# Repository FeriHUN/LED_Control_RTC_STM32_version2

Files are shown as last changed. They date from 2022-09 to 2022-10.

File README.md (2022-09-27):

# LED_Control_RTC_STM32_version2
20 channel 16 bit PWM LED strip brightness controller for 12-24V applications with RS485 connectivity

[Expander board link](https://github.com/FeriHUN/LED_Control_RTC_STM32_version2_Expander)



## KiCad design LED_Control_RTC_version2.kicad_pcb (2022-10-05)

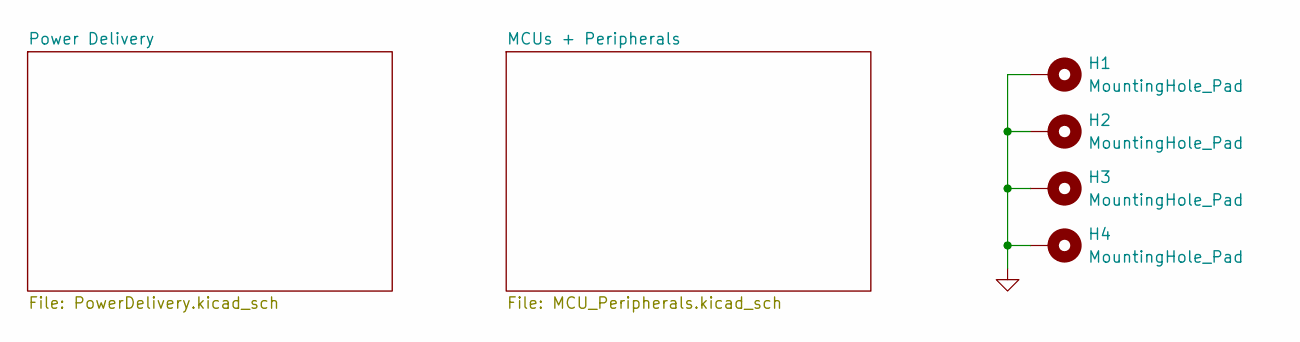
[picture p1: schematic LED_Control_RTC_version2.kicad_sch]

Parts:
H1, H2, H3, H4: MountingHole_Pad; MountingHole_3.2mm_M3_Pad_Via

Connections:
GND: H1.1, H2.1, H3.1, H4.1; also elsewhere on the board

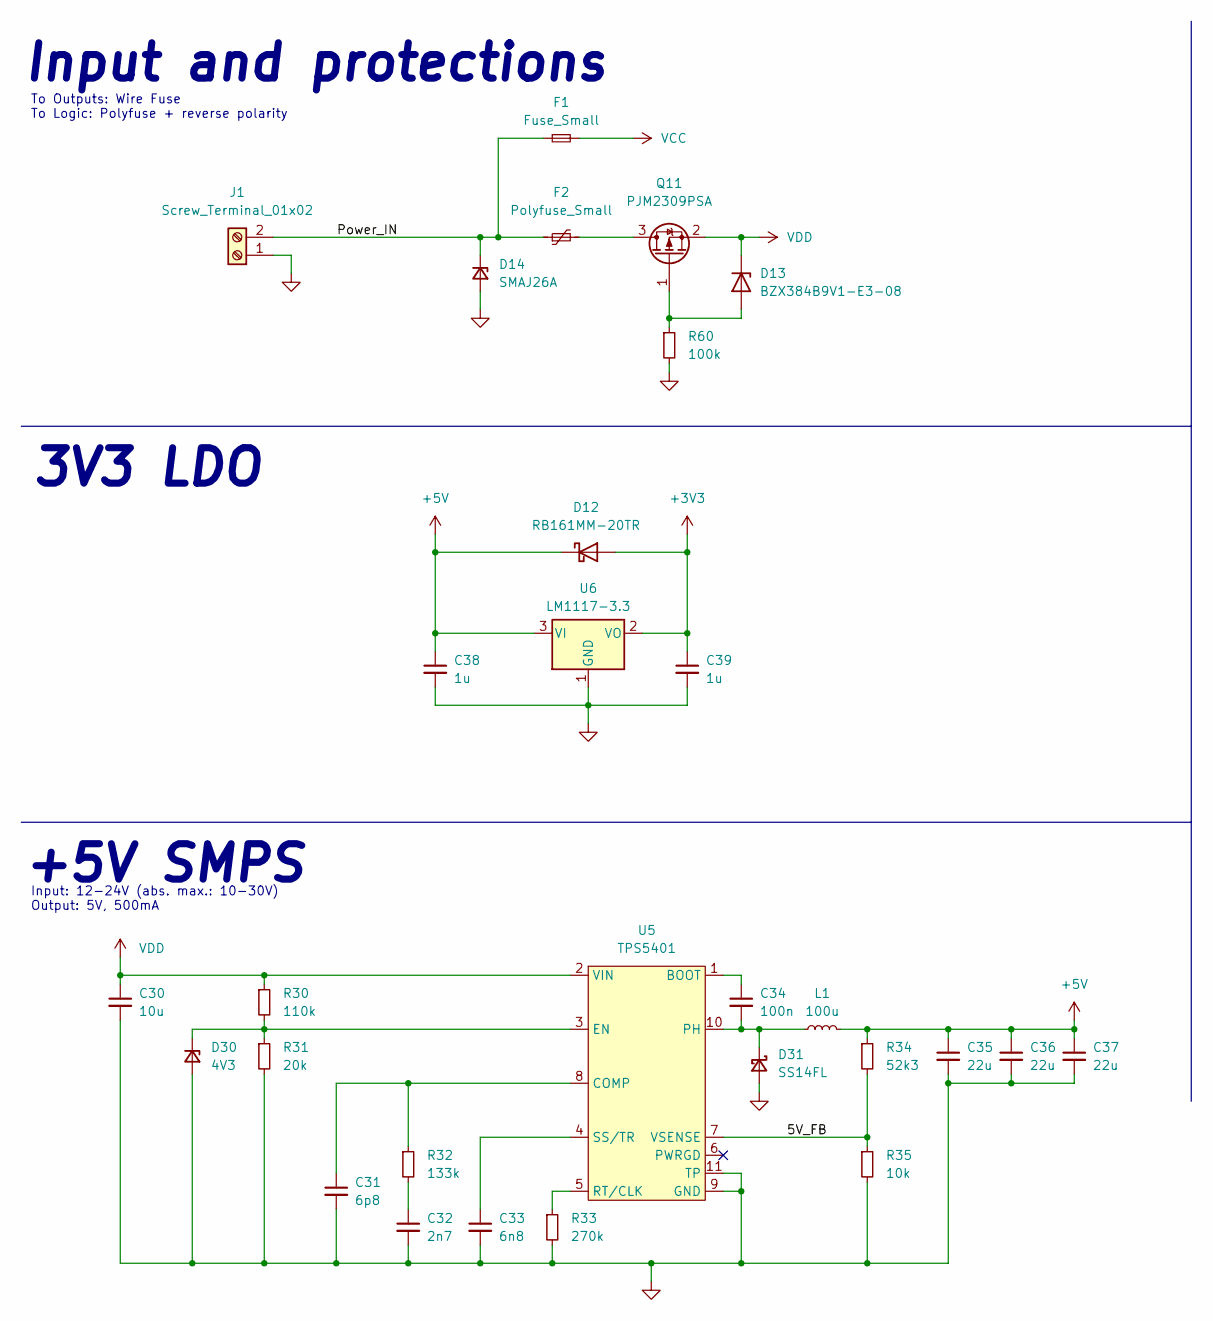
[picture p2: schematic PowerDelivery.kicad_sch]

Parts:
C30: 10u; R_1206_3216Metric
C31: 6p8; R_0603_1608Metric
C32: 2n7; R_0603_1608Metric
C33: 6n8; R_0603_1608Metric
C34: 100n; R_0603_1608Metric
C35, C36, C37: 22u; R_1206_3216Metric
C38, C39: 1u; C_0603_1608Metric
D12: RB161MM-20TR; D_SOD-123F
D13: BZX384B9V1-E3-08; D_SOD-323
D14: SMAJ26A; D_SMA
D30: 4V3; D_SOD-123
D31: SS14FL; D_SMA
F1: Fuse_Small; Fuseholder_Littelfuse_100_series_5x20mm
F2: Polyfuse_Small; Fuse_1812_4532Metric
J1: Screw_Terminal_01x02; PhoenixContact_MC_1,5_2-GF-5.08_1x02_P5.08mm_Horizontal_Thr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
L1: 100u; ABG08A40M101
Q11: PJM2309PSA; SOT-23
R30: 110k; R_0603_1608Metric
R31: 20k; R_0603_1608Metric
R32: 133k; R_0603_1608Metric
R33: 270k; R_0603_1608Metric
R34: 52k3; R_0603_1608Metric
R35: 10k; R_0603_1608Metric
R60: 100k; R_0402_1005Metric
U5: TPS5401; MSOP-10-1EP_3x3mm_P0.5mm_EP1.68x1.88mm_ThermalVias
U6: LM1117-3.3; SOT-223-3_TabPin2

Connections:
+5V: C35.1, C36.1, C37.1, C38.1, D12.1 (K), L1.2, R34.1, U6.3 (VI); also elsewhere on the board
/Power Delivery/5V_FB: R34.2, R35.1, U5.7 (VSENSE)
/Power Delivery/Power_IN: D14.1 (K), F1.1, F2.1, J1.2
GND: C30.2, C31.2, C32.2, C33.2, C35.2, C36.2, C37.2, C38.2, C39.2, D14.2 (A), D30.2 (A), D31.2 (A), J1.1, R31.2, R33.2, R35.2, R60.2, U5.9 (GND), U5.11 (TP), U6.1 (GND); also elsewhere on the board
unnamed: C31.1, R32.1, U5.8 (COMP)
unnamed: C32.1, R32.2
unnamed: C33.1, U5.4 (SS/TR)
unnamed: C34.1, U5.1 (BOOT)
unnamed: C34.2, D31.1 (K), L1.1, U5.10 (PH)
unnamed: D13.2 (A), Q11.1 (G), R60.1
unnamed: D30.1 (K), R30.2, R31.1, U5.3 (EN)
unnamed: F2.2, Q11.3 (D)
unnamed: R33.1, U5.5 (RT/CLK)
VCC: F1.2; also elsewhere on the board
VDD: C30.1, D13.1 (K), Q11.2 (S), R30.1, U5.2 (VIN)

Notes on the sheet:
+5V SMPS
Input: 12-24V (abs. max.: 10-30V) Output: 5V, 500mA
3V3 LDO
Input and protections
To Outputs: Wire Fuse To Logic: Polyfuse + reverse polarity

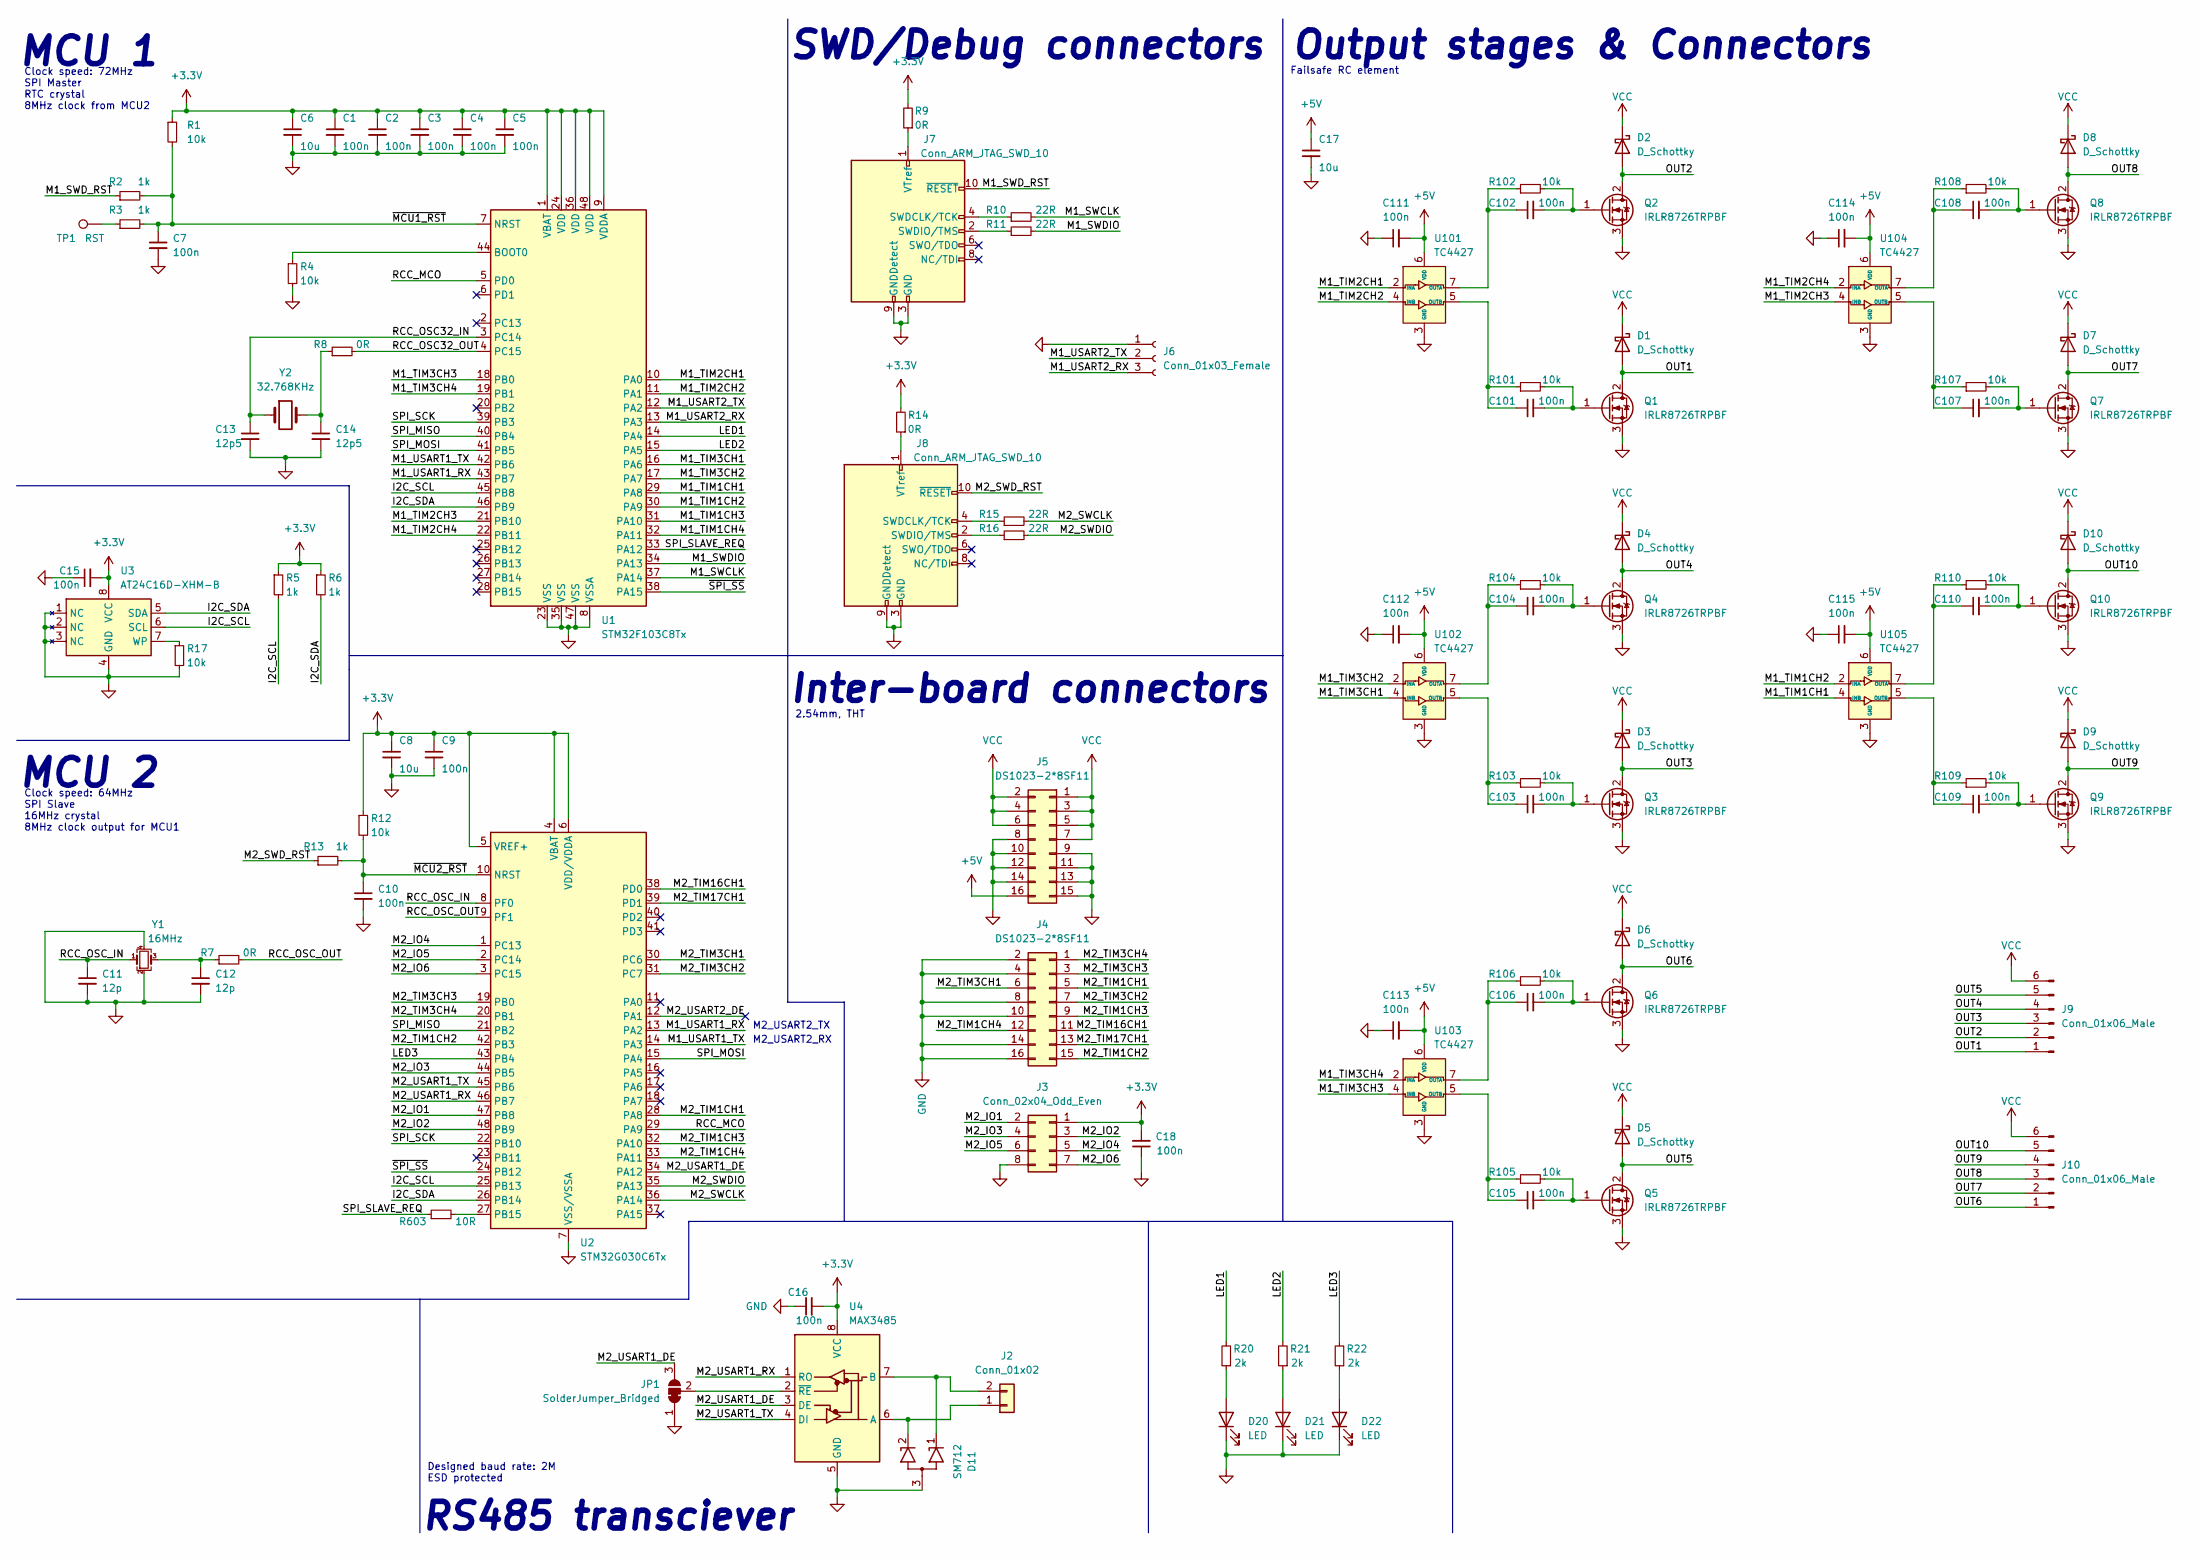
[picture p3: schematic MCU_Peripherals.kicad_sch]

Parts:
C1, C2, C3, C4, C5, C7, C9, C10, C15, C16, C18, C101, C102, C103, C104, C105, C106, C107, C108, C109, C110, C111, C112, C113, C114, C115: 100n; C_0402_1005Metric
C6, C8, C17: 10u; R_1206_3216Metric
C11, C12: 12p; C_0402_1005Metric
C13, C14: 12p5; C_0402_1005Metric
D1, D2, D3, D4, D5, D6, D7, D8, D9, D10: D_Schottky; D_SMA
D11: SM712; SOT-23
D20, D21, D22: LED; LED_1206_3216Metric
J2: Conn_01x02; DB2ERC-2.54-2P-GN
J3: Conn_02x04_Odd_Even; PinSocket_2x04_P2.54mm_Vertical
J4, J5: DS1023-2*8SF11; PinSocket_2x08_P2.54mm_Vertical
J6: Conn_01x03_Female; PinSocket_1x03_P2.54mm_Vertical
J7, J8: Conn_ARM_JTAG_SWD_10; PinHeader_2x05_P1.27mm_Vertical_SMD
J9, J10: Conn_01x06_Male; PhoenixContact_MCV_1,5_6-GF-3.81_1x06_P3.81mm_Vertical_Thre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
JP1: SolderJumper_Bridged; SolderJumper-3_P1.3mm_Bridged12_Pad1.0x1.5mm
Q1, Q2, Q3, Q4, Q5, Q6, Q7, Q8, Q9, Q10: IRLR8726TRPBF; TO-252-2
R1, R4, R12, R17, R101, R102, R103, R104, R105, R106, R107, R108, R109, R110: 10k; R_0402_1005Metric
R2, R3, R5, R6, R13: 1k; R_0402_1005Metric
R7, R8, R9, R14: 0R; R_0402_1005Metric
R10, R11, R15, R16: 22R; R_0402_1005Metric
R20, R21, R22: 2k; R_0402_1005Metric
R603: 10R; R_0402_1005Metric
TP1: RST; TestPoint_Pad_D1.0mm
U1: STM32F103C8Tx; LQFP-48_7x7mm_P0.5mm
U2: STM32G030C6Tx; LQFP-48_7x7mm_P0.5mm
U3: AT24C16D-XHM-B; TSSOP-8_4.4x3mm_P0.65mm
U4: MAX3485; SOP-8_3.9x4.9mm_P1.27mm
U101, U102, U103, U104, U105: TC4427; SOIC-8_3.9x4.9mm_P1.27mm
Y1: 16MHz; Crystal_SMD_3225-4Pin_3.2x2.5mm
Y2: 32.768KHz; Crystal_SMD_3215-2Pin_3.2x1.5mm

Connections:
+5V: C17.1, C111.2, C112.2, C113.2, C114.2, C115.2, J5.16, U101.6 (VDD), U102.6 (VDD), U103.6 (VDD), U104.6 (VDD), U105.6 (VDD); also elsewhere on the board
/MCUs + Peripherals/I2C_SCL: R5.2, U1.45 (PB8), U2.25 (PB13), U3.6 (SCL)
/MCUs + Peripherals/I2C_SDA: R6.2, U1.46 (PB9), U2.26 (PB14), U3.5 (SDA)
/MCUs + Peripherals/LED1: R20.2, U1.14 (PA4)
/MCUs + Peripherals/LED2: R21.2, U1.15 (PA5)
/MCUs + Peripherals/LED3: R22.2, U2.43 (PB4)
/MCUs + Peripherals/M1_SWCLK: R10.2, U1.37 (PA14)
/MCUs + Peripherals/M1_SWDIO: R11.2, U1.34 (PA13)
/MCUs + Peripherals/M1_SWD_RST: J7.10 (~RESET), R2.1
/MCUs + Peripherals/M1_TIM1CH1: U1.29 (PA8), U105.4 (INB)
/MCUs + Peripherals/M1_TIM1CH2: U1.30 (PA9), U105.2 (INA)
/MCUs + Peripherals/M1_TIM1CH3: U1.31 (PA10)
/MCUs + Peripherals/M1_TIM1CH4: U1.32 (PA11)
/MCUs + Peripherals/M1_TIM2CH1: U1.10 (PA0), U101.2 (INA)
/MCUs + Peripherals/M1_TIM2CH2: U1.11 (PA1), U101.4 (INB)
/MCUs + Peripherals/M1_TIM2CH3: U1.21 (PB10), U104.4 (INB)
/MCUs + Peripherals/M1_TIM2CH4: U1.22 (PB11), U104.2 (INA)
/MCUs + Peripherals/M1_TIM3CH1: U1.16 (PA6), U102.4 (INB)
/MCUs + Peripherals/M1_TIM3CH2: U1.17 (PA7), U102.2 (INA)
/MCUs + Peripherals/M1_TIM3CH3: U1.18 (PB0), U103.4 (INB)
/MCUs + Peripherals/M1_TIM3CH4: U1.19 (PB1), U103.2 (INA)
/MCUs + Peripherals/M1_USART1_RX: U1.43 (PB7), U2.13 (PA2)
/MCUs + Peripherals/M1_USART1_TX: U1.42 (PB6), U2.14 (PA3)
/MCUs + Peripherals/M1_USART2_RX: J6.3, U1.13 (PA3)
/MCUs + Peripherals/M1_USART2_TX: J6.2, U1.12 (PA2)
/MCUs + Peripherals/M2_IO1: J3.2, U2.47 (PB8)
/MCUs + Peripherals/M2_IO2: J3.3, U2.48 (PB9)
/MCUs + Peripherals/M2_IO3: J3.4, U2.44 (PB5)
/MCUs + Peripherals/M2_IO4: J3.5, U2.1 (PC13)
/MCUs + Peripherals/M2_IO5: J3.6, U2.2 (PC14)
/MCUs + Peripherals/M2_IO6: J3.7, U2.3 (PC15)
/MCUs + Peripherals/M2_SWCLK: R15.2, U2.36 (PA14)
/MCUs + Peripherals/M2_SWDIO: R16.2, U2.35 (PA13)
/MCUs + Peripherals/M2_SWD_RST: J8.10 (~RESET), R13.1
/MCUs + Peripherals/M2_TIM1CH1: J4.5, U2.28 (PA8)
/MCUs + Peripherals/M2_TIM1CH2: J4.15, U2.42 (PB3)
/MCUs + Peripherals/M2_TIM1CH3: J4.9, U2.32 (PA10)
/MCUs + Peripherals/M2_TIM1CH4: J4.12, U2.33 (PA11)
/MCUs + Peripherals/M2_TIM3CH1: J4.6, U2.30 (PC6)
/MCUs + Peripherals/M2_TIM3CH2: J4.7, U2.31 (PC7)
/MCUs + Peripherals/M2_TIM3CH3: J4.3, U2.19 (PB0)
/MCUs + Peripherals/M2_TIM3CH4: J4.1, U2.20 (PB1)
/MCUs + Peripherals/M2_TIM16CH1: J4.11, U2.38 (PD0)
/MCUs + Peripherals/M2_TIM17CH1: J4.13, U2.39 (PD1)
/MCUs + Peripherals/M2_USART1_DE: JP1.3 (B), U2.34 (PA12), U4.3 (DE)
/MCUs + Peripherals/M2_USART1_RX: U2.46 (PB7), U4.1 (RO)
/MCUs + Peripherals/M2_USART1_TX: U2.45 (PB6), U4.4 (DI)
/MCUs + Peripherals/M2_USART2_DE: U2.12 (PA1)
/MCUs + Peripherals/OUT1: D1.2 (A), J9.1, Q1.2 (D)
/MCUs + Peripherals/OUT2: D2.2 (A), J9.2, Q2.2 (D)
/MCUs + Peripherals/OUT3: D3.2 (A), J9.3, Q3.2 (D)
/MCUs + Peripherals/OUT4: D4.2 (A), J9.4, Q4.2 (D)
/MCUs + Peripherals/OUT5: D5.2 (A), J9.5, Q5.2 (D)
/MCUs + Peripherals/OUT6: D6.2 (A), J10.1, Q6.2 (D)
/MCUs + Peripherals/OUT7: D7.2 (A), J10.2, Q7.2 (D)
/MCUs + Peripherals/OUT8: D8.2 (A), J10.3, Q8.2 (D)
/MCUs + Peripherals/OUT9: D9.2 (A), J10.4, Q9.2 (D)
/MCUs + Peripherals/OUT10: D10.2 (A), J10.5, Q10.2 (D)
/MCUs + Peripherals/RCC_MCO: U1.5 (PD0), U2.29 (PA9)
/MCUs + Peripherals/RCC_OSC32_IN: C13.1, U1.3 (PC14), Y2.1
/MCUs + Peripherals/RCC_OSC32_OUT: R8.2, U1.4 (PC15)
/MCUs + Peripherals/RCC_OSC_IN: C11.1, U2.8 (PF0), Y1.1
/MCUs + Peripherals/RCC_OSC_OUT: R7.2, U2.9 (PF1)
/MCUs + Peripherals/SPI_MISO: U1.40 (PB4), U2.21 (PB2)
/MCUs + Peripherals/SPI_MOSI: U1.41 (PB5), U2.15 (PA4)
/MCUs + Peripherals/SPI_SCK: U1.39 (PB3), U2.22 (PB10)
/MCUs + Peripherals/SPI_SLAVE_REQ: R603.1, U1.33 (PA12)
/MCUs + Peripherals/~MCU1_RST: C7.1, R1.2, R2.2, R3.2, U1.7 (NRST)
/MCUs + Peripherals/~MCU2_RST: C10.1, R12.2, R13.2, U2.10 (NRST)
/MCUs + Peripherals/~SPI_SS: U1.38 (PA15), U2.24 (PB12)
GND: C1.2, C2.2, C3.2, C4.2, C5.2, C6.2, C7.2, C8.2, C9.2, C10.2, C11.2, C12.2, C13.2, C14.2, C15.1, C16.1, C17.2, C18.1, C111.1, C112.1, C113.1, C114.1, C115.1, D11.3 (A), D20.1 (K), D21.1 (K), D22.1 (K), J3.8, J4.2, J4.4, J4.8, J4.10, J4.14, J4.16, J5.8, J5.9, J5.10, J5.11, J5.12, J5.13, J5.14, J5.15, J6.1, J7.3 (GND), J7.5 (GND), J7.9 (GNDDetect), J8.3 (GND), J8.5 (GND), J8.9 (GNDDetect), JP1.1 (A), Q1.3 (S), Q2.3 (S), Q3.3 (S), Q4.3 (S), Q5.3 (S), Q6.3 (S), Q7.3 (S), Q8.3 (S), Q9.3 (S), Q10.3 (S), R4.2, R17.2, U1.8 (VSSA), U1.23 (VSS), U1.35 (VSS), U1.47 (VSS), U2.7 (VSS/VSSA), U3.1 (NC), U3.2 (NC), U3.3 (NC), U3.4 (GND), U4.5 (GND), U101.3 (GND), U102.3 (GND), U103.3 (GND), U104.3 (GND), U105.3 (GND), Y1.2, Y1.4; also elsewhere on the board
unnamed: C12.1, R7.1, Y1.3
unnamed: C14.1, R8.1, Y2.2
unnamed: C101.1, R101.1, U101.5 (OUTB)
unnamed: C101.2, Q1.1 (G), R101.2
unnamed: C102.1, R102.1, U101.7 (OUTA)
unnamed: C102.2, Q2.1 (G), R102.2
unnamed: C103.1, R103.1, U102.5 (OUTB)
unnamed: C103.2, Q3.1 (G), R103.2
unnamed: C104.1, R104.1, U102.7 (OUTA)
unnamed: C104.2, Q4.1 (G), R104.2
unnamed: C105.1, R105.1, U103.5 (OUTB)
unnamed: C105.2, Q5.1 (G), R105.2
unnamed: C106.1, R106.1, U103.7 (OUTA)
unnamed: C106.2, Q6.1 (G), R106.2
unnamed: C107.1, R107.1, U104.5 (OUTB)
unnamed: C107.2, Q7.1 (G), R107.2
unnamed: C108.1, R108.1, U104.7 (OUTA)
unnamed: C108.2, Q8.1 (G), R108.2
unnamed: C109.1, R109.1, U105.5 (OUTB)
unnamed: C109.2, Q9.1 (G), R109.2
unnamed: C110.1, R110.1, U105.7 (OUTA)
unnamed: C110.2, Q10.1 (G), R110.2
unnamed: D11.1 (K1), J2.2, U4.7 (B)
unnamed: D11.2 (K2), J2.1, U4.6 (A)
unnamed: D20.2 (A), R20.1
unnamed: D21.2 (A), R21.1
unnamed: D22.2 (A), R22.1
unnamed: J7.1 (VTref), R9.1
unnamed: J7.2 (SWDIO/TMS), R11.1
unnamed: J7.4 (SWDCLK/TCK), R10.1
unnamed: J8.1 (VTref), R14.1
unnamed: J8.2 (SWDIO/TMS), R16.1
unnamed: J8.4 (SWDCLK/TCK), R15.1
unnamed: JP1.2 (C), U4.2 (~RE)
unnamed: R3.1, TP1.1
unnamed: R4.1, U1.44 (BOOT0)
unnamed: R17.1, U3.7 (WP)
unnamed: R603.2, U2.27 (PB15)
VCC: D1.1 (K), D2.1 (K), D3.1 (K), D4.1 (K), D5.1 (K), D6.1 (K), D7.1 (K), D8.1 (K), D9.1 (K), D10.1 (K), J5.1, J5.2, J5.3, J5.4, J5.5, J5.6, J5.7, J9.6, J10.6; also elsewhere on the board

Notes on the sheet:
Failsafe RC element
Inter-board connectors
Clock speed: 72MHz SPI Master RTC crystal 8MHz clock from MCU2
Clock speed: 64MHz SPI Slave 16MHz crystal 8MHz clock output for MCU1
M2_USART2_TX
SWD/Debug connectors
MCU 1
RS485 transciever
2.54mm, THT
Designed baud rate: 2M ESD protected
Output stages & Connectors
M2_USART2_RX
MCU 2

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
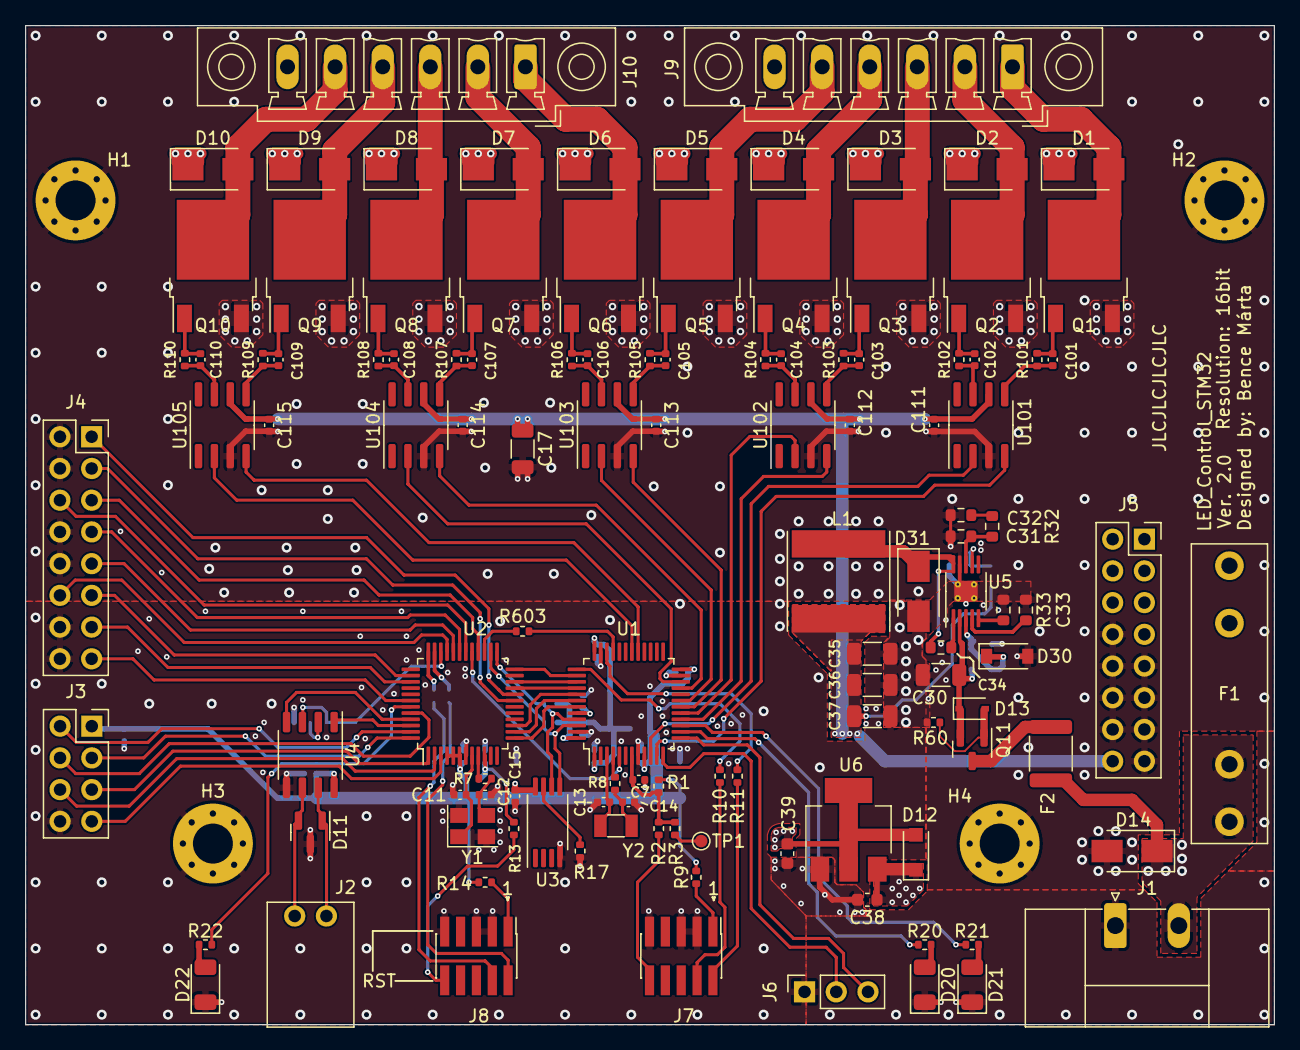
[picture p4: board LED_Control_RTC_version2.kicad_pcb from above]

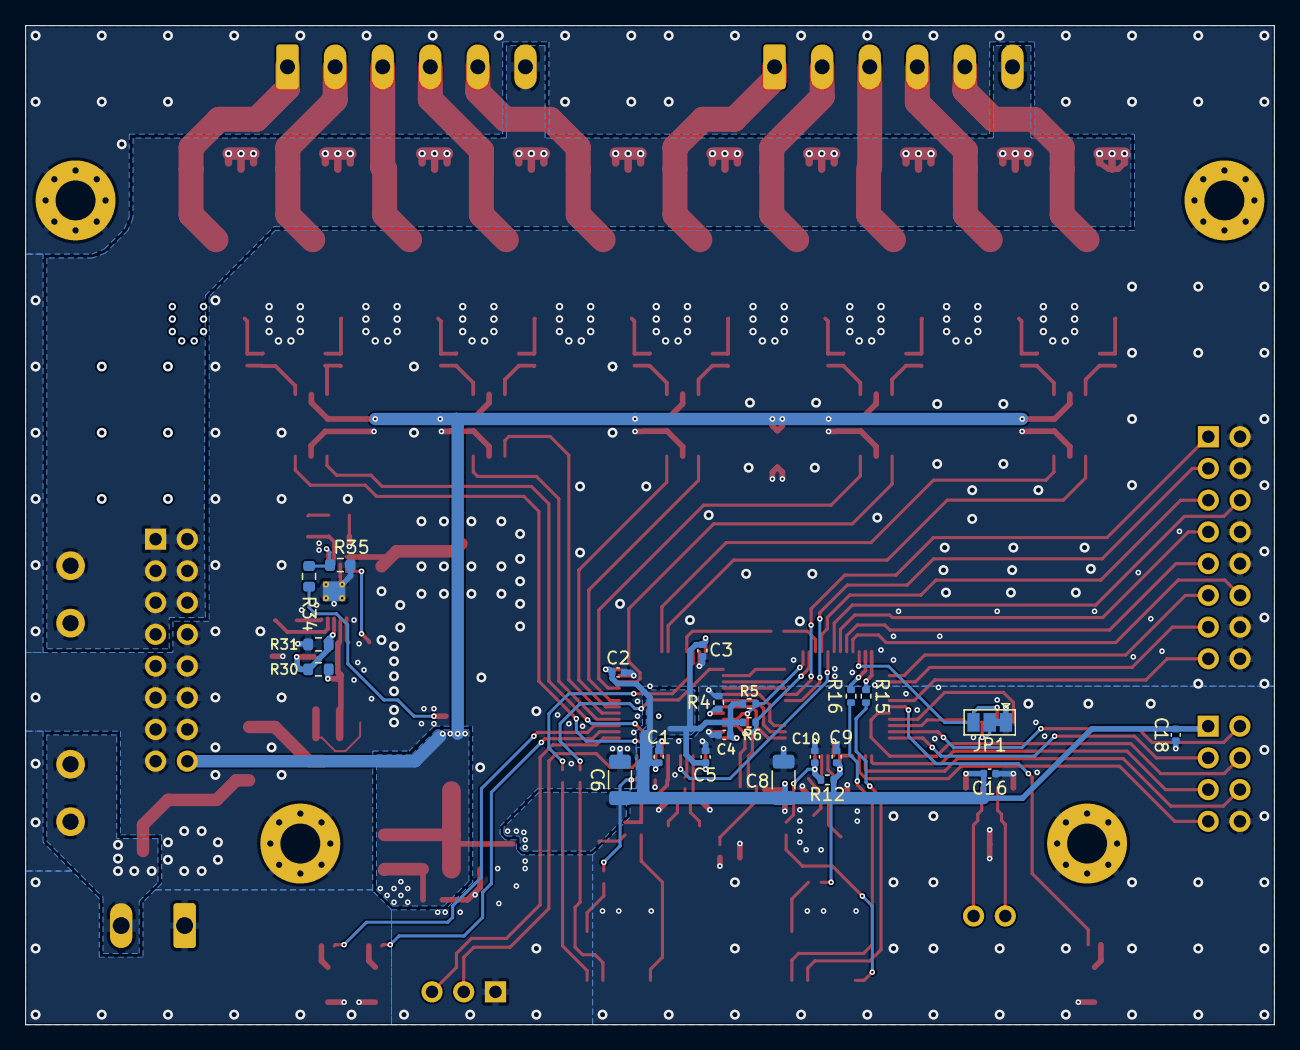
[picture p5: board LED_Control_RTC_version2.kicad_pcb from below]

Board: 4 copper layers, 100.0 x 80.0 mm, 143 parts (22 on the bottom side), 120 nets.

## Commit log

2022-09-09 INitial files commit
    [LED_Control_RTC_version2.kicad_pcb, LED_Control_RTC_version2.kicad_sch, MCU_Peripherals.kicad_sch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]
2022-09-10 Cleaned up messy reference numbering Added labels to schematic
    [LED_Control_RTC_version2.kicad_pcb, LED_Control_RTC_version2.kicad_sch, MCU_Peripherals.kicad_sch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]
2022-09-10 Added TVS diode on power input
    [LED_Control_RTC_version2.kicad_pcb, LED_Control_RTC_version2.kicad_sch, PowerDelivery.kicad_sch]
2022-09-11 Added more GND vias
    [LED_Control_RTC_version2.kicad_pcb]
2022-09-13 Added FET driver cap
    [LED_Control_RTC_version2.kicad_pcb, LED_Control_RTC_version2.kicad_sch, MCU_Peripherals.kicad_sch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]
2022-09-16 Ready for prod
    [LED_Control_RTC_version2.kicad_pcb, MCU_Peripherals.kicad_sch]
2022-09-18 Added interactive BOM (bom/ibom.html)
2022-10-05 Corrected bad footprint of RS485 connector
    [LED_Control_RTC_version2.kicad_pcb]
